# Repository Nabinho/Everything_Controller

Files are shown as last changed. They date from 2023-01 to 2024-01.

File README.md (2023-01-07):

# Everything_Controller
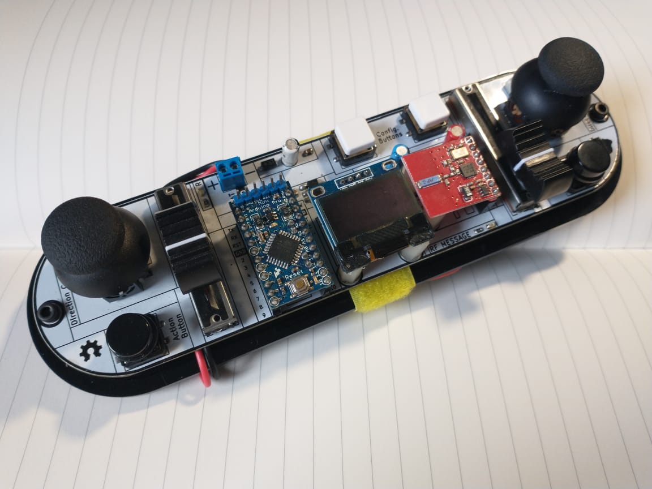
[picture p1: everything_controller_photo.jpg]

Arduino and RF24 based controller to control different types of robots. The codes (controller and receptor example) are available in the "Software" folder, and the electronic project (KiCad project) is available in the "Hardware" folder.

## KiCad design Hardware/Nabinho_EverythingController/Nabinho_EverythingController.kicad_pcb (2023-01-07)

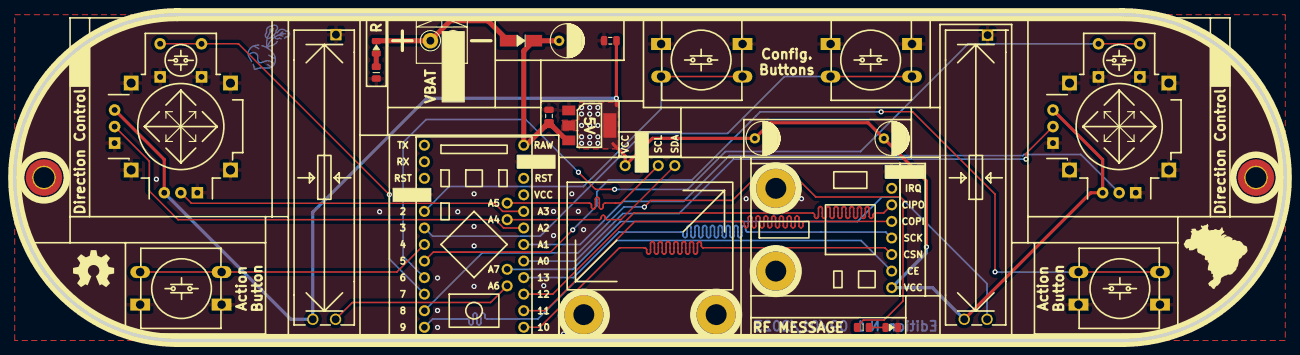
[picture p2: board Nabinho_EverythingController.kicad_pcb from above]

Board: 2 copper layers, 195.0 x 50.0 mm, 25 parts (0 on the bottom side), 26 nets.

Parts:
C1, C2, C4: 0.1uF; CP_Radial_D5.0mm_P2.50mm
C3, C5: 1uF; C_0805_2012Metric
D1, D3: RED; LED_0805_2012Metric
D2: SS34; D_SMA
Ge: LOGO; opensourceh
J1: NRF24L01; Sparkfun_NRF24L01
J2: 0.96_OLED
J3: Conn_01x02; TerminalBlock_4Ucon_1x02_P3.50mm_Horizontal
R1, R2: 1k; R_0805_2012Metric
RV1, RV2: Slider; Potentiometer_Bourns_PTA3043_Single_Slide
SW1, SW2, SW3, SW4: SW_Push; SW_PUSH-12mm
U1: BB_ProMini; Sparkfun_ProMini
U2: AMS1117-5.0; SOT-223-3_TabPin2
U3, U4: Joystick; XDCR_COM-09032
e: LOGO; brazil

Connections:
+5V: C1.1, C2.1, C5.1, J1.1, J2.1, RV1.1, RV2.1, U2.2 (VO), U3.H1 (H+), U3.V1 (V+), U4.H1 (H+), U4.V1 (V+)
BTN1: SW1.1, U1.5 (2)
BTN2: SW2.1, U1.6 (3)
BTN3: SW3.1, U1.7 (4)
BTN4: SW4.1, U1.8 (5)
CE: J1.2, U1.12 (9)
CIPO: J1.6, U1.19 (12)
COPI: J1.5, U1.18 (11)
CSN: J1.3, U1.17 (10)
GND: C1.2, C2.2, C3.2, C4.2, C5.2, D3.1 (K), J1.8, J2.2, J3.1, R1.1, RV1.3, RV2.3, SW1.2, SW2.2, SW3.2, SW4.2, U1.4 (GND), U1.27 (GND), U2.1 (GND), U3.B2A (SEL-), U3.B2B, U3.H3 (H-), U3.S1 (SHIELD), U3.S2 (SHIELD), U3.S3 (SHIELD), U3.S4 (SHIELD), U3.V3 (V-), U4.B2A (SEL-), U4.B2B, U4.H3 (H-), U4.S1 (SHIELD), U4.S2 (SHIELD), U4.S3 (SHIELD), U4.S4 (SHIELD), U4.V3 (V-)
JOY_X1: U1.21 (A0), U4.V2 (V)
JOY_X2: U1.23 (A2), U3.V2 (V)
JOY_Y1: U1.22 (A1), U4.H2 (H)
JOY_Y2: U1.4 (GND), U3.H2 (H)
J_BTN1: U1.9 (6), U4.B1A (SEL+), U4.B1B
J_BTN2: U1.10 (7), U3.B1A (SEL+), U3.B1B
LED1: R2.1, U1.11 (8)
unnamed: D1.1 (K), D2.2 (A), J3.2
unnamed: D1.2 (A), R1.2
unnamed: D3.2 (A), R2.2
SCK: J1.4, U1.20 (13)
SCL: J2.3, U1.13 (A5)
SDA: J2.4, U1.14 (A4)
SLIDER1: RV2.2, U1.16 (A7)
SLIDER2: RV1.2, U1.15 (A6)
VBUS: C3.1, C4.1, D2.1 (K), U1.28 (VIN), U2.3 (VI)

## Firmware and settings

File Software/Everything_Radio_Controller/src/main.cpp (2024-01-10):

/*******************************************************************************
 * Everything Controller (v1.0)
 *
 * Base code for the "Everything Controller" to send data to a receiver.
 * Communication is based on RF24 using the NRF24L01+ module. The controller
 * sends data from 6 digital buttons, 2 joysticks (2 X-axis and 2 Y-axis), as
 * well as the analog readings from two sliders. With this data, it is possible
 * to control various robots.
 *
 * Written by Giovanni de Castro (19/11/2023).
 *
 * This program is free software: you can redistribute it and/or modify
 * it under the terms of the GNU Lesser General Public License as published by
 * the Free Software Foundation, either version 3 of the License, or
 * (at your option) any later version (<https://www.gnu.org/licenses/>).
 *******************************************************************************/

// Libraries
#include <SPI.h>
#include <RF24.h>
#include <Wire.h>
#include <Arduino.h>
#include <Adafruit_GFX.h>
#include <Adafruit_SSD1306.h>

// ------------------------------------------------------------------------------
// Control pins of the radio module
const uint8_t PIN_CE = 9;
const uint8_t PIN_CSN = 10;

// Control variables of the OLED display
const uint8_t DISPLAY_ADDRESS = 0x3C;
const uint8_t DISPLAY_WIDTH = 128;
const uint8_t DISPLAY_HEIGHT = 64;
const int8_t DISPLAY_RESET = -1;

// Control pins of the LEDs
const uint8_t LED_STATUS = 8;
const uint8_t LED_L = 13;

// Controller address
const uint8_t RADIO_ADDRESSES[][6] = {"Ctrlr", "Robot"};

// Radio number
const uint8_t RADIO_NUMBER = 0;

// Creation of the radio module control object
RF24 radio(PIN_CE, PIN_CSN);

// Creation of the display control object
Adafruit_SSD1306 display(DISPLAY_WIDTH, DISPLAY_HEIGHT, &Wire, DISPLAY_RESET);

// Variables for reading the button
const uint8_t BUTTON1_PIN = 2;
bool button1_reading;
bool output1_state = LOW;
bool button1_state;
bool last_button1_state = HIGH;
unsigned long last_debounce1 = 0;

// Variables for reading the button
const uint8_t BUTTON2_PIN = 3;
bool button2_reading;
bool output2_state = LOW;
bool button2_state;
bool last_button2_state = HIGH;
unsigned long last_debounce2 = 0;

// Variables for reading the button
const uint8_t BUTTON3_PIN = 4;
bool button3_reading;
bool output3_state = LOW;
bool button3_state;
bool last_button3_state = HIGH;
unsigned long last_debounce3 = 0;

// Variables for reading the button
const uint8_t BUTTON4_PIN = 5;
bool button4_reading;
bool output4_state = LOW;
bool button4_state;
bool last_button4_state = HIGH;
unsigned long last_debounce4 = 0;

// Variables for reading the button
const uint8_t BUTTON5_PIN = 6;
bool button5_reading;
bool output5_state = LOW;
bool button5_state;
bool last_button5_state = HIGH;
unsigned long last_debounce5 = 0;

// Variables for reading the button
const uint8_t BUTTON6_PIN = 7;
bool button6_reading;
bool output6_state = HIGH;
bool button6_state;
bool last_button6_state = HIGH;
unsigned long last_debounce6 = 0;

// Variable for buttons debounce
const uint8_t DEBOUNCE = 50;

// Variables for analog reading
const uint8_t ANALOG1_PIN = A0;
uint16_t analog1_reading;

// Variables for analog reading
const uint8_t ANALOG2_PIN = A1;
uint16_t analog2_reading;

// Variables for analog reading
const uint8_t ANALOG3_PIN = A2;
uint16_t analog3_reading;

// Variables for analog reading
const uint8_t ANALOG4_PIN = A3;
uint16_t analog4_reading;

// Variables for analog reading
const uint8_t ANALOG5_PIN = A6;
uint16_t analog5_reading;

// Variables for analog reading
const uint8_t ANALOG6_PIN = A7;
uint16_t analog6_reading;

// Variables for analog readings mappings
uint16_t joysticks_mapping[4] = {0, 0, 0, 0};
uint16_t sliders_mapping[2] = {0, 0};

// Variables for variables transmission timing
unsigned long last_millis = 0;
const uint8_t TX_INTERVAL = 50;
unsigned long last_message = millis();
const uint16_t TX_TIMEOUT = 500;

// Variables structure
typedef struct
{
  uint8_t button1_reading;
  uint8_t button2_reading;
  uint8_t button3_reading;
  uint8_t button4_reading;
  uint8_t button5_reading;
  uint8_t button6_reading;
  uint16_t X1axis_reading;
  uint16_t Y1axis_reading;
  uint16_t X2axis_reading;
  uint16_t Y2axis_reading;
  uint16_t slider1_reading;
  uint16_t slider2_reading;
} controller_variables;
controller_variables controller;

// Lost signal image
const unsigned char lost_signal[] PROGMEM = {
    0xff, 0xff, 0xff, 0xff, 0xff, 0xff, 0xff, 0xff, 0xff, 0xff, 0xff, 0xff, 0xff, 0xff, 0xff, 0xff,
    0xff, 0xff, 0xff, 0xff, 0xff, 0xff, 0xff, 0xff, 0xff, 0xff, 0xff, 0xff, 0xff, 0xff, 0xff, 0xff,
    0xff, 0xff, 0xff, 0xff, 0xff, 0xff, 0xff, 0xff, 0xff, 0xff, 0xff, 0xff, 0xff, 0xff, 0xff, 0xff,
    0xff, 0xff, 0xff, 0xff, 0xff, 0xff, 0xff, 0xff, 0xff, 0xff, 0xff, 0xff, 0xff, 0xff, 0xff, 0xff,
    0xff, 0xff, 0xff, 0xff, 0xff, 0xff, 0xff, 0xff, 0xff, 0xff, 0xff, 0xff, 0xff, 0xff, 0xff, 0xff,
    0xff, 0xff, 0xff, 0xff, 0xff, 0xff, 0xff, 0xff, 0xff, 0xff, 0xff, 0xff, 0xff, 0xff, 0xff, 0xff,
    0xff, 0xff, 0xff, 0xff, 0xff, 0xff, 0xff, 0xff, 0xff, 0xff, 0x3f, 0xff, 0xff, 0xff, 0xff, 0xff,
    0xff, 0xff, 0xff, 0xff, 0xff, 0xff, 0xff, 0xff, 0xff, 0xfe, 0x1f, 0xff, 0xff, 0xff, 0xff, 0xff,
    0xff, 0xff, 0xff, 0xff, 0xff, 0xff, 0xff, 0xff, 0xff, 0xfe, 0x1f, 0xff, 0xff, 0xff, 0xff, 0xff,
    0xff, 0xff, 0xff, 0xff, 0xff, 0xff, 0xff, 0xff, 0xff, 0xfe, 0x1f, 0xff, 0xff, 0xff, 0xff, 0xff,
    0xff, 0xff, 0xff, 0xff, 0xff, 0xff, 0xff, 0xff, 0xff, 0xfe, 0x1f, 0xff, 0xff, 0xff, 0xff, 0xff,
    0xff, 0xff, 0xff, 0xff, 0xff, 0xff, 0xff, 0xff, 0xff, 0xfe, 0x1f, 0xff, 0xff, 0xff, 0xff, 0xff,
    0xff, 0xff, 0xff, 0xff, 0xff, 0xff, 0xff, 0xff, 0xff, 0xfe, 0x1f, 0xff, 0xff, 0xff, 0xff, 0xff,
    0xff, 0xff, 0xff, 0xff, 0xff, 0xff, 0xff, 0xff, 0xff, 0xfe, 0x1f, 0xff, 0xff, 0xff, 0xff, 0xff,
    0xff, 0xff, 0xff, 0xff, 0xff, 0xff, 0xff, 0xff, 0xff, 0xfe, 0x1f, 0xff, 0xff, 0xff, 0xff, 0xff,
    0xff, 0xff, 0xff, 0xff, 0xff, 0xff, 0xff, 0xff, 0xff, 0xfe, 0x1f, 0xff, 0xff, 0xff, 0xff, 0xff,
    0xff, 0xff, 0xff, 0xff, 0xff, 0xff, 0xff, 0xff, 0xf0, 0xfe, 0x1f, 0xff, 0xff, 0xff, 0xff, 0xff,
    0xff, 0xff, 0xff, 0xff, 0xff, 0xff, 0xff, 0xff, 0xf0, 0xfe, 0x1f, 0xff, 0xff, 0xff, 0xff, 0xff,
    0xff, 0xff, 0xff, 0xff, 0xff, 0xff, 0xff, 0xff, 0xf0, 0xfe, 0x1f, 0xff, 0xff, 0xff, 0xff, 0xff,
    0xff, 0xff, 0xff, 0xff, 0xff, 0xff, 0xff, 0xff, 0xf0, 0xfe, 0x1f, 0xff, 0xff, 0xff, 0xff, 0xff,
    0xff, 0xff, 0xff, 0xff, 0xff, 0xff, 0xff, 0xff, 0xf0, 0xfe, 0x1f, 0xff, 0xff, 0xff, 0xff, 0xff,
    0xff, 0xff, 0xff, 0xff, 0xff, 0xff, 0xff, 0xff, 0xf0, 0xfe, 0x1f, 0xff, 0xff, 0xff, 0xff, 0xff,
    0xff, 0xff, 0xff, 0xff, 0xff, 0xff, 0xff, 0xff, 0xf0, 0xfe, 0x1f, 0xff, 0xff, 0xff, 0xff, 0xff,
    0xff, 0xff, 0xff, 0xff, 0xff, 0xff, 0xff, 0xff, 0xf0, 0xfe, 0x1f, 0xff, 0xff, 0xff, 0xff, 0xff,
    0xff, 0xff, 0xff, 0xff, 0xff, 0xff, 0xff, 0xff, 0xf0, 0xfe, 0x1f, 0xff, 0xff, 0xff, 0xff, 0xff,
    0xff, 0xff, 0xff, 0xff, 0xff, 0xff, 0xff, 0xcf, 0xf0, 0xc6, 0x1f, 0xff, 0xff, 0xff, 0xff, 0xff,
    0xff, 0xff, 0xff, 0xff, 0xff, 0xff, 0xff, 0x87, 0xf0, 0x86, 0x1f, 0xff, 0xff, 0xff, 0xff, 0xff,
    0xff, 0xff, 0xff, 0xff, 0xff, 0xff, 0xff, 0x87, 0xf0, 0x82, 0x1f, 0xff, 0xff, 0xff, 0xff, 0xff,
    0xff, 0xff, 0xff, 0xff, 0xff, 0xff, 0xff, 0x87, 0xf0, 0x02, 0x1f, 0xff, 0xff, 0xff, 0xff, 0xff,
    0xff, 0xff, 0xff, 0xff, 0xff, 0xff, 0xff, 0x87, 0xf0, 0x00, 0x1f, 0xff, 0xff, 0xff, 0xff, 0xff,
    0xff, 0xff, 0xff, 0xff, 0xff, 0xff, 0xff, 0x87, 0xf0, 0x00, 0x1f, 0xff, 0xff, 0xff, 0xff, 0xff,
    0xff, 0xff, 0xff, 0xff, 0xff, 0xff, 0xff, 0x87, 0xf0, 0x10, 0x1f, 0xff, 0xff, 0xff, 0xff, 0xff,
    0xff, 0xff, 0xff, 0xff, 0xff, 0xff, 0xff, 0x87, 0xf0, 0x30, 0x1f, 0xff, 0xff, 0xff, 0xff, 0xff,
    0xff, 0xff, 0xff, 0xff, 0xff, 0xff, 0xff, 0x87, 0xf0, 0x38, 0x1f, 0xff, 0xff, 0xff, 0xff, 0xff,
    0xff, 0xff, 0xff, 0xff, 0xff, 0xff, 0xff, 0x87, 0xf0, 0x78, 0x1f, 0xff, 0xff, 0xff, 0xff, 0xff,
    0xff, 0xff, 0xff, 0xff, 0xff, 0xfc, 0x7f, 0x87, 0xf0, 0x7c, 0x1f, 0xff, 0xff, 0xff, 0xff, 0xff,
    0xff, 0xff, 0xff, 0xff, 0xff, 0xfc, 0x3f, 0x87, 0xf0, 0xfe, 0x1f, 0xff, 0xff, 0xff, 0xff, 0xff,
    0xff, 0xff, 0xff, 0xff, 0xff, 0xfc, 0x3f, 0x87, 0xf0, 0xfe, 0x1f, 0xff, 0xff, 0xff, 0xff, 0xff,
    0xff, 0xff, 0xff, 0xff, 0xff, 0xfc, 0x3f, 0x87, 0xe1, 0xc7, 0x0f, 0xff, 0xff, 0xff, 0xff, 0xff,
    0xff, 0xff, 0xff, 0xff, 0xff, 0xfc, 0x3f, 0x87, 0xe1, 0xc7, 0x0f, 0xff, 0xff, 0xff, 0xff, 0xff,
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

// ------------------------------------------------------------------------------
// Function to display a progress bar for the sliders
void drawSliderPosition(int x, int y, int width, int height, int progress)
{
  float bar = ((float)(height - 4) / 100) * progress;
  display.drawRoundRect(x, y, width, height, 5, WHITE);
  display.fillRoundRect(x + 2, y + 2, width - 4, height - 4, 2, WHITE);
  display.fillRoundRect(x + 2, y + 2, width - 4, bar, 2, BLACK);
}

// ------------------------------------------------------------------------------
// Function to draw startup progressa bar
void drawProgressBar(int x, int y, int width, int height, int progress)
{
  progress = progress > 100 ? 100 : progress;
  progress = progress < 0 ? 0 : progress;
  float bar = ((float)(width - 4) / 100) * progress;
  display.drawRoundRect(x, y, width, height, 5, WHITE);
  display.fillRoundRect(x + 2, y + 2, bar, height - 4, 2, WHITE);
}

// ------------------------------------------------------------------------------
// Function to display buttons states
void drawButtonState(int x, int y, int width, int height, bool state)
{
  display.drawRoundRect(x, y, width, height, 5, WHITE);
  if (state)
  {
    display.fillRoundRect(x + 2, y + 2, width - 4, height - 4, 2, WHITE);
  }
}

// ------------------------------------------------------------------------------
// Function to display the joysticks positions
void drawJoyPosition(int x, int y, int radius, int px, int py)
{
  display.drawLine(x, (y + radius) - 4, x, (y - radius) + 4, WHITE);
  display.drawLine((x + radius) - 4, y, (x - radius) + 4, y, WHITE);
  display.drawRoundRect(x - radius, y - radius, (radius * 2) + 1, (radius * 2) + 1, 5, WHITE);
  display.drawCircle(x, y, radius, WHITE);
  display.fillCircle(px, py, radius / 10, WHITE);
}

// ------------------------------------------------------------------------------
void setup()
{

  // Serial monitor initialization for debug
  Serial.begin(9600);

  // LEDs configuration and initialization
  pinMode(LED_STATUS, OUTPUT);
  digitalWrite(LED_STATUS, LOW);

  // OLED display initialization
  if (!display.begin(SSD1306_SWITCHCAPVCC, DISPLAY_ADDRESS))
  {
    Serial.println(F("DISPLAY INITIALIZATION FAILED!!!"));
    while (!display.begin(SSD1306_SWITCHCAPVCC, DISPLAY_ADDRESS))
    {
      Serial.println(F("."));
      // Blinks alert LED
      digitalWrite(LED_L, !digitalRead(LED_L));
      delay(100);
    }
  }

  // Clears the display from last usage
  display.clearDisplay();
  display.setTextColor(WHITE);
  display.setTextSize(1);
  display.setCursor(4, 0);
  display.println("Starting");
  drawProgressBar(4, 32, 120, 10, 10);
  display.display();
  delay(250);

  // Radio module initialization
  if (!radio.begin())
  {
    Serial.println(F("RADIO INITIALIZATION FAILED!!!"));
    while (!radio.begin())
    {
      Serial.println(F("."));
      // Blinks alert LED
      digitalWrite(LED_L, !digitalRead(LED_L));
      delay(250);
    }
  }

  // Clears the display from last usage
  display.clearDisplay();
  display.setTextColor(WHITE);
  display.setTextSize(1);
  display.setCursor(4, 0);
  display.println("Starting.");
  drawProgressBar(4, 32, 120, 10, 35);
  display.display();
  delay(100);

  // Configure the radio for maximum PA level
  radio.setPALevel(RF24_PA_MAX);

  // Set the maximum waiting time for data transmission to be equal to the maximum size of the message to be sent
  radio.setPayloadSize(sizeof(controller));

  // Configuration of the transmission channels
  radio.openWritingPipe(RADIO_ADDRESSES[RADIO_NUMBER]);
  radio.openReadingPipe(1, RADIO_ADDRESSES[!RADIO_NUMBER]);

  // Initializes the radio as transmitter
  radio.stopListening();

  // Clears the display from last usage
  display.clearDisplay();
  display.setTextColor(WHITE);
  display.setTextSize(1);
  display.setCursor(4, 0);
  display.println("Starting..");
  drawProgressBar(4, 32, 120, 10, 60);
  display.display();
  delay(100);

  // Buttons configuration
  pinMode(BUTTON1_PIN, INPUT_PULLUP);
  pinMode(BUTTON2_PIN, INPUT_PULLUP);
  pinMode(BUTTON3_PIN, INPUT_PULLUP);
  pinMode(BUTTON4_PIN, INPUT_PULLUP);
  pinMode(BUTTON5_PIN, INPUT_PULLUP);
  pinMode(BUTTON6_PIN, INPUT_PULLUP);

  // Clears the display from last usage
  display.clearDisplay();
  display.setTextColor(WHITE);
  display.setTextSize(1);
  display.setCursor(4, 0);
  display.println("Starting...");
  drawProgressBar(4, 32, 120, 10, 85);
  display.display();
  delay(100);

  // Analog pins configuration
  pinMode(ANALOG1_PIN, INPUT);
  pinMode(ANALOG2_PIN, INPUT);
  pinMode(ANALOG3_PIN, INPUT);
  pinMode(ANALOG4_PIN, INPUT);
  pinMode(ANALOG5_PIN, INPUT);
  pinMode(ANALOG6_PIN, INPUT);

  // Clears the display from last usage
  display.clearDisplay();
  display.setTextColor(WHITE);
  display.setTextSize(1);
  display.setCursor(4, 0);
  display.println("Done!");
  drawProgressBar(4, 32, 120, 10, 100);
  display.display();
  delay(250);
}

// ------------------------------------------------------------------------------
void loop()
{

  // Blinks the LED
  digitalWrite(LED_STATUS, LOW);

  // Reads the button
  button1_reading = digitalRead(BUTTON1_PIN);
  if (button1_reading != last_button1_state)
  {
    last_debounce1 = millis();
  }
  if ((millis() - last_debounce1) > DEBOUNCE)
  {
    if (button1_reading != button1_state)
    {
      button1_state = button1_reading;
      if (button1_state == LOW)
      {
        output1_state = !output1_state;
      }
    }
  }
  last_button1_state = button1_reading;

  // Reads analog pin
  analog1_reading = analogRead(ANALOG1_PIN);

  // Reads the button
  button2_reading = digitalRead(BUTTON2_PIN);
  if (button2_reading != last_button2_state)
  {
    last_debounce2 = millis();
  }
  if ((millis() - last_debounce2) > DEBOUNCE)
  {
    if (button2_reading != button2_state)
    {
      button2_state = button2_reading;
      if (button2_state == LOW)
      {
        output2_state = !output2_state;
      }
    }
  }
  last_button2_state = button2_reading;

  // Reads analog pin
  analog2_reading = analogRead(ANALOG2_PIN);

  // Reads the button
  button3_reading = digitalRead(BUTTON3_PIN);
  if (button3_reading != last_button3_state)
  {
    last_debounce3 = millis();
  }
  if ((millis() - last_debounce3) > DEBOUNCE)
  {
    if (button3_reading != button3_state)
    {
      button3_state = button3_reading;
      if (button3_state == LOW)
      {
        output3_state = !output3_state;
      }
    }
  }
  last_button3_state = button3_reading;

  // Reads analog pin
  analog3_reading = analogRead(ANALOG3_PIN);

  // Reads the button
  button4_reading = digitalRead(BUTTON4_PIN);
  if (button4_reading != last_button4_state)
  {
    last_debounce4 = millis();
  }
  if ((millis() - last_debounce4) > DEBOUNCE)
  {
    if (button4_reading != button4_state)
    {
      button4_state = button4_reading;
      if (button4_state == LOW)
      {
        output4_state = !output4_state;
      }
    }
  }
  last_button4_state = button4_reading;

  // Reads analog pin
  analog4_reading = analogRead(ANALOG4_PIN);

  // Reads the button
  button5_reading = digitalRead(BUTTON5_PIN);
  if (button5_reading != last_button5_state)
  {
    last_debounce5 = millis();
  }
  if ((millis() - last_debounce5) > DEBOUNCE)
  {
    if (button5_reading != button5_state)
    {
      button5_state = button5_reading;
      if (button5_state == LOW)
      {
        output5_state = true;
      }
      else
      {
        output5_state = false;
      }
    }
  }
  last_button5_state = button5_reading;

  // Reads analog pin
  analog5_reading = analogRead(ANALOG5_PIN);

  // Reads the button
  button6_reading = digitalRead(BUTTON6_PIN);
  if (button6_reading != last_button6_state)
  {
    last_debounce6 = millis();
  }
  if ((millis() - last_debounce6) > DEBOUNCE)
  {
    if (button6_reading != button6_state)
    {
      button6_state = button6_reading;
      if (button6_state == LOW)
      {
        output6_state = true;
      }
      else
      {
        output6_state = false;
      }
    }
  }
  last_button6_state = button6_reading;

  // Reads analog pin
  analog6_reading = analogRead(ANALOG6_PIN);

  // Maps the progress bars to the readings of the sliders
  sliders_mapping[0] = map(analog5_reading, 0, 1000, 0, 100);
  sliders_mapping[1] = map(analog6_reading, 0, 1023, 0, 100);

  // Maps the readings of the joysticks to valid positions within the display circles
  joysticks_mapping[0] = map(analog4_reading, 0, 1023, 40, 8);   // X1
  joysticks_mapping[1] = map(analog3_reading, 0, 1023, 47, 15);  // Y1
  joysticks_mapping[2] = map(analog2_reading, 0, 1023, 117, 85); // X2
  joysticks_mapping[3] = map(analog1_reading, 0, 1023, 47, 15);  // Y2

  // Updates the variables for transmission
  controller.button1_reading = output1_state;
  controller.button2_reading = output2_state;
  controller.button3_reading = output3_state;
  controller.button4_reading = output4_state;
  controller.button5_reading = output5_state;
  controller.button6_reading = output6_state;
  controller.X1axis_reading = analog4_reading;
  controller.Y1axis_reading = analog3_reading;
  controller.X2axis_reading = analog2_reading;
  controller.Y2axis_reading = analog1_reading;
  controller.slider1_reading = analog5_reading;
  controller.slider2_reading = analog6_reading;

  if ((millis() - last_millis) > TX_INTERVAL)
  {

    // Clears display
    display.clearDisplay();

    // Sends the data and checks for reception
    bool sent = radio.write(&controller, sizeof(controller));

    if (sent)
    {
      // Updates and displays progress bars
      digitalWrite(LED_STATUS, HIGH);
      last_message = millis();
      display.invertDisplay(false);
      drawSliderPosition(52, 10, 10, 44, sliders_mapping[0]);
      drawSliderPosition(64, 10, 10, 44, sliders_mapping[1]);

      // Updates and displays the joysticks positions
      drawJoyPosition(24, 31, 20, joysticks_mapping[0], joysticks_mapping[1]);
      drawJoyPosition(101, 31, 20, joysticks_mapping[2], joysticks_mapping[3]);

      // Updates and displays the buttons states
      drawButtonState(2, 0, 60, 10, output1_state);
      drawButtonState(64, 0, 60, 10, output2_state);
      drawButtonState(2, 54, 29, 10, output3_state);
      drawButtonState(33, 54, 29, 10, output6_state);
      drawButtonState(64, 54, 29, 10, output5_state);
      drawButtonState(95, 54, 29, 10, output4_state);
    }
    else if ((millis() - last_message) > TX_TIMEOUT)
    {
      // Displays lost signal image
      display.invertDisplay(true);
      display.drawBitmap(0, 0, lost_signal, 128, 64, 1);
    }

    // Shows displays update
    display.display();
    last_millis = millis();
  }
}
// ------------------------------------------------------------------------------

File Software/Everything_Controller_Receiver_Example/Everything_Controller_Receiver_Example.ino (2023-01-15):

/*******************************************************************************
* Everything Controller - Exemplo Bascio de Receptor (v1.0)
* 
* Codigo basico de exemplo de receptor para recepcao de dados do controle
* "Everything Controller" baseado em comunicacao RF24 atraves do modulo NRF24L01+.
* O controle envia dados de 6 botoes digitais, 2 joysticks (2 eixos X e 2 eixos Y),
* assim como a leitura analogica de dois sliders.
* Com esses dados e possivel o controle de diversos robos.
* 
* Escrito por Giovanni de Castro (07/01/2023).
* 
* This program is free software: you can redistribute it and/or modify
* it under the terms of the GNU Lesser General Public License as published by
* the Free Software Foundation, either version 3 of the License, or
* (at your option) any later version (<https://www.gnu.org/licenses/>).
*******************************************************************************/

// Bibliotecas
#include <SPI.h>
#include "printf.h"
#include "RF24.h"

// Criacao do objeto de controle do radio receptor
RF24 radio(9, 10); // 9 -> CE | 10 -> CSN

// Enderecos dos radios (controle e receptor (robo))
uint8_t address[][6] = { "Ctrlr", "Robot" };

// Numero do radio no conjunto (controle -> 0 | receptor -> 1)
const bool radioNumber = 1;

// Estrutura de variaveis que sao trnamitidas pelo radio
typedef struct {
  uint8_t leitura_botao1;
  uint8_t leitura_botao2;
  uint8_t leitura_botao3;
  uint8_t leitura_botao4;
  uint8_t leitura_botao5;
  uint8_t leitura_botao6;
  uint16_t leitura_eixoX1;
  uint16_t leitura_eixoY1;
  uint16_t leitura_eixoX2;
  uint16_t leitura_eixoY2;
  uint16_t leitura_Slide1;
  uint16_t leitura_Slide2;
} variaveis_mensagem;
variaveis_mensagem controle;

// Variaveis para o recebimento de mensagens
uint8_t canal;
uint8_t bytes;

// Configuracoes de codigo
void setup() {

  // Inicializacao do monitor serial para verificar dados recebidos
  Serial.begin(9600);

  // Inicializacao da comunicacao SPI e do radio
  if (!radio.begin()) {
    Serial.println(F("Falha na inicializacao do radio"));
    while (1) {}  // hold in infinite loop
  }

  // Configura o radio para operar em baixo consumo de energia
  radio.setPALevel(RF24_PA_MAX);

  // Configura o radio para aguardar o tempo maximo igual ao tamanho da estrutura que sera recebida
  radio.setPayloadSize(sizeof(controle));

  // Configura o canal de escrita do radio, para retornar mensagens ao radio, se precisar
  radio.openWritingPipe(address[radioNumber]);

  // Configura o canal que o radio ira receber as mensagens
  radio.openReadingPipe(1, address[!radioNumber]);

  // Comanda o radio para iniciar o recebimento de mensagens
  radio.startListening();

}

// Repeticao do codigo
void loop() {

  
  if (radio.available(&canal)) 
  {
    bytes = radio.getPayloadSize();
    radio.read(&controle, bytes);
    Serial.print(F("Mensagem de "));
    Serial.print(bytes);
    Serial.print(F(" bytes recebida no canal "));
    Serial.print(canal);
    Serial.println(F(" conteudo : "));
    Serial.print(controle.leitura_botao1);
    Serial.print(F(" | "));
    Serial.print(controle.leitura_botao2);
    Serial.print(F(" | "));
    Serial.print(controle.leitura_botao3);
    Serial.print(F(" | "));
    Serial.print(controle.leitura_botao4);
    Serial.print(F(" | "));
    Serial.print(controle.leitura_botao5);
    Serial.print(F(" | "));
    Serial.println(controle.leitura_botao6);
    Serial.print(controle.leitura_eixoX1);
    Serial.print(F(" | "));
    Serial.print(controle.leitura_eixoY1);
    Serial.print(F(" | "));
    Serial.print(controle.leitura_eixoX2);
    Serial.print(F(" | "));
    Serial.print(controle.leitura_eixoY2);
    Serial.print(F(" | "));
    Serial.print(controle.leitura_Slide1);
    Serial.print(F(" | "));
    Serial.println(controle.leitura_Slide2);
  }
}
